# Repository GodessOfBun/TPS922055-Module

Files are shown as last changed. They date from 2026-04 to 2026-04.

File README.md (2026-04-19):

### If you find this project helpful please consider buying me coffee
<a href="https://ko-fi.com/ameliabun">
KofiRainbowMug_56
</a>
</br>
</br>
This is a work in progress. The prototype has not confirmed to work or function well yet.
This module is designed with 48v VIN in mind, but can be used for  any voltages lower, the inductor can be calculated for every scenario using https://www.schemalyzer.com/en/tools/buck-converter-calculator.
Default operation frequency is 1.2Mhz but can be lowered to 600KHz for lower heat if space allows.
This design uses a 4 layer PCB which is very affordable at JLCPCB as long as the inner layers are 0.5oz. 

The module requires a 300uf~ bulk cap (perferrabily polymer) close to  VIN on the main PCB. Ensure the area under the module is grounded to reduce EMI if possible.



Silkscreen is removed over certain sections of ground to improve heat transfer. A heatsink will be required on the backside depending on the required load. Use a non-conductive thermal tape to adhere the heatsink to the PCB as the VCC and GND vias are both exposed on the backside. If not in use, cover with kapton tape. I have to figure out how to get KiCad to only cover the VCC vias...

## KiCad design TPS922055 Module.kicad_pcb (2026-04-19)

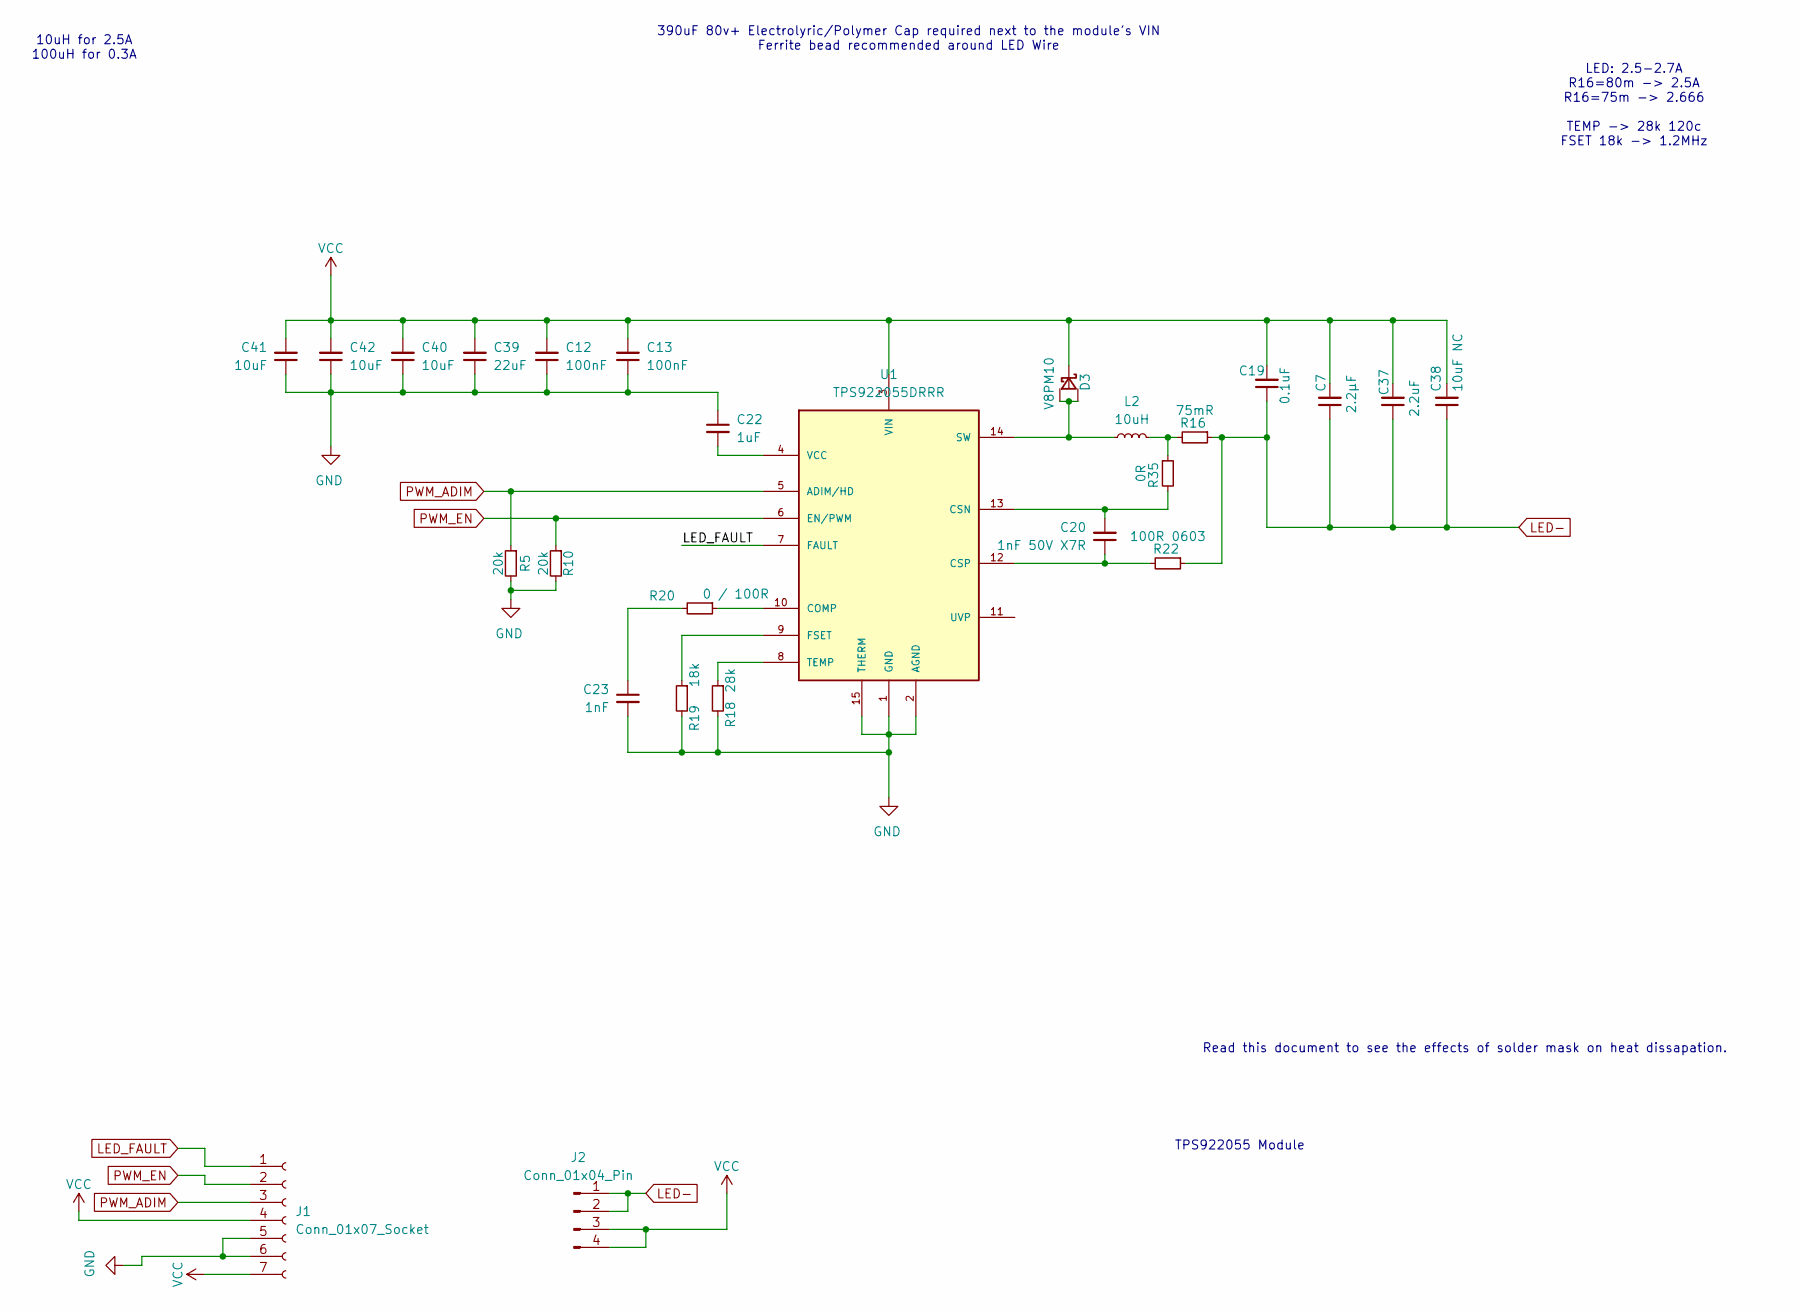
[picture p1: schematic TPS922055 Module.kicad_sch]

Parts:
C7: 2.2µF; C_1210_3225Metric
C12, C13: 100nF; C_0805_2012Metric
C19: 0.1uF; C_0805_2012Metric
C20: 1nF 50V X7R; C_0402_1005Metric
C22: 1uF; C_1206_3216Metric
C23: 1nF; C_0402_1005Metric
C37: 2.2uF; C_1210_3225Metric
C38: 10uF NC; C_1210_3225Metric
C39: 22uF; C_2220_5750Metric
C40, C41, C42: 10uF; C_1210_3225Metric
D3: V8PM10; TO-277A
J1: Conn_01x07_Socket; PinSocket_1x07_P2.54mm_Vertical
J2: Conn_01x04_Pin; PinSocket_1x04_P2.54mm_Vertical
L2: 10uH; L_Panasonic_PCC-M0754M
R5, R10: 20k; R_0603_1608Metric
R16: 75mR; R_2512_6332Metric
R18: 28k; R_0603_1608Metric
R19: 18k; R_0603_1608Metric
R20: 0 / 100R; R_0603_1608Metric
R22: 100R 0603; R_0603_1608Metric
R35: 0R; R_0603_1608Metric
U1: TPS922055DRRR; TPS922055DMTR; PARTREV A

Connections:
GND: C12.1, C13.1, C22.1, C23.2, C39.1, C40.1, C41.1, C42.1, J1.5, J1.6, R5.2, R10.2, R18.2, R19.2, U1.1 (GND), U1.2 (AGND), U1.15 (THERM)
LED-: C7.1, C19.1, C37.1, C38.1, J2.1, J2.2, R16.1, R22.1
LED_FAULT: J1.1, U1.7 (FAULT)
unnamed: C23.1, R20.2
unnamed: D3.1 (rA), D3.2 (A), L2.1, U1.14 (SW)
unnamed: L2.2, R16.2, R35.1
unnamed: R20.1, U1.10 (COMP)
unnamed: C20.2, R35.2, U1.13 (CSN)
unnamed: C20.1, R22.2, U1.12 (CSP)
unnamed: R19.1, U1.9 (FSET)
unnamed: R18.1, U1.8 (TEMP)
unnamed: C22.2, U1.4 (VCC)
PWM_ADIM: J1.3, R5.1, U1.5 (ADIM/HD)
PWM_EN: J1.2, R10.1, U1.6 (EN/PWM)
VCC: C7.2, C12.2, C13.2, C19.2, C37.2, C38.2, C39.2, C40.2, C41.2, C42.2, D3.3 (K), J1.4, J1.7, J2.3, J2.4, U1.3 (VIN)

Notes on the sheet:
Read this document to see the effects of solder mask on heat dissapation.
LED: 2.5-2.7A R16=80m -> 2.5A R16=75m -> 2.666 TEMP -> 28k 120c FSET 18k -> 1.2MHz
10uH for 2.5A 100uH for 0.3A
TPS922055 Module
390uF 80v+ Electrolyric/Polymer Cap required next to the module's VIN Ferrite bead recommended around LED Wire

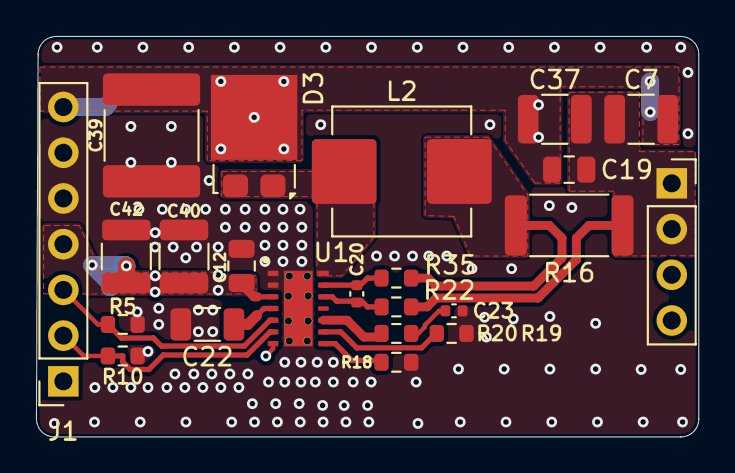
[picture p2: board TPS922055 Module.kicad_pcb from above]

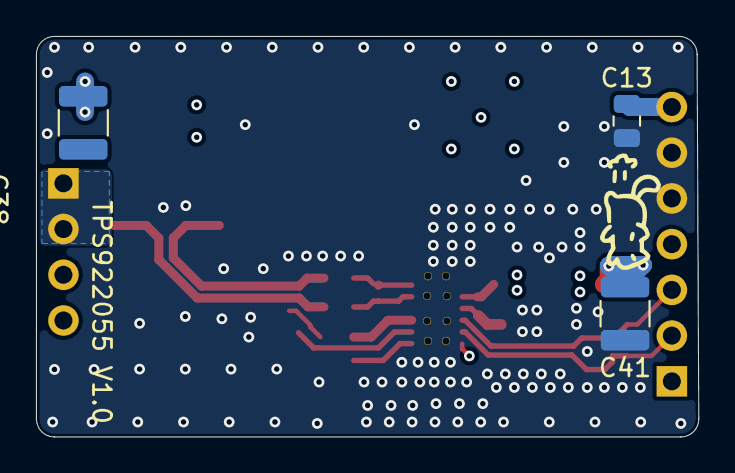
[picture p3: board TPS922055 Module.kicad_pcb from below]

Board: 4 copper layers, 36.8 x 22.2 mm, 26 parts (3 on the bottom side), 15 nets.
